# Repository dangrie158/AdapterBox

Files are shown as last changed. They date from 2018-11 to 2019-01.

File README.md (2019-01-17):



# Adapter Box

A simple multiconnector Adapter Box to hopefully fulfill all connection needs. It features 2 Channels (e.g. +/-) and the following connectors:

- 1x 5.5mm / 2.1mm DC-Jack (center positive)
- 1x USB-A
- 1x Phoenix Contact MKDSN Screw Terminals (0.2" / 5.08mm Pitch)
- 4x (2 per Channel) 4mm Banana Jack
- 4x (2 per Channel) 6.3mm Spade Terminal Connector
- 2x (1 per Channel) 5.5mm / 6.3mm Contact Point (e.g. for Crocodile Clips)
- 1x BNC (vertical mounting)
- 12x (6 per Channel) Female Pinheader (0.1" / 2,57mm Pitch)
- 12x (6 per Channel) Male Pinheader (0.1" / 2,57mm Pitch)
- 1x Power LED

The Power LED is driven my an LM334 constant current source that can handle up to 40V and 20V in reverse polarity. If you plan on going any higher, don't populate the components.

## Renders
### Assembly
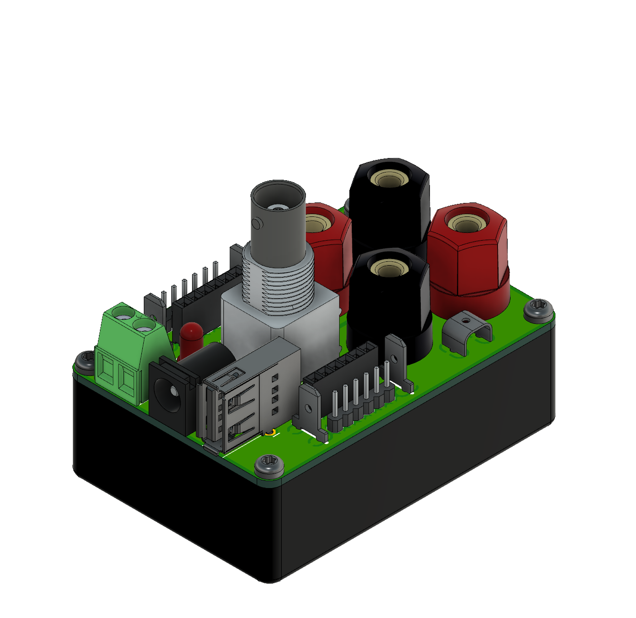
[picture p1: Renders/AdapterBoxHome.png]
Home View

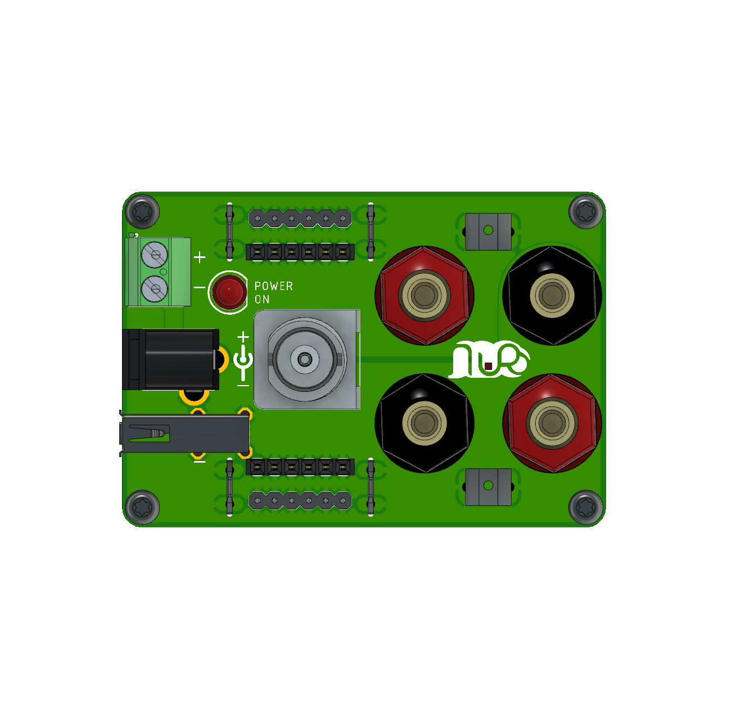
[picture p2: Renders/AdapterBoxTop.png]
Top View

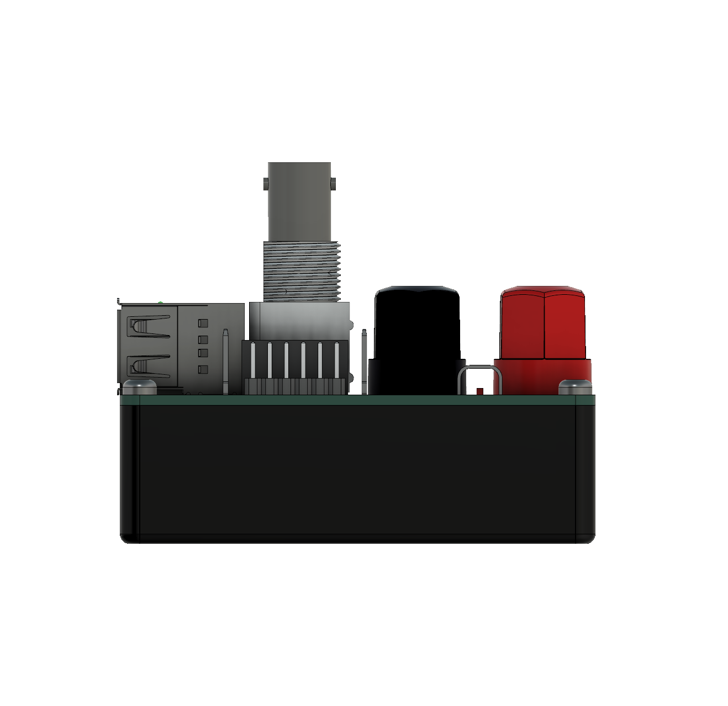
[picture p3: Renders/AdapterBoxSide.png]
Side View


### Board
#### Topside:
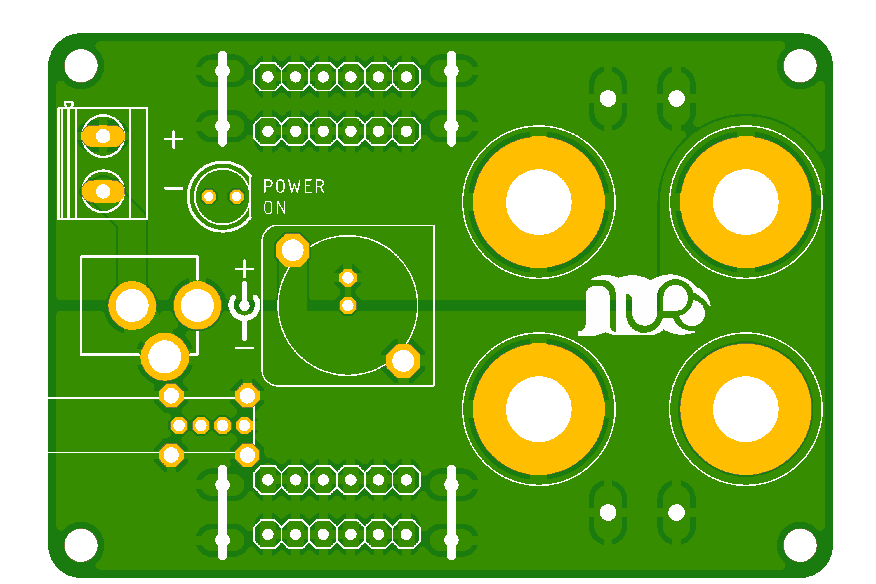
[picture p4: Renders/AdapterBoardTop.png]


#### Bottomside:
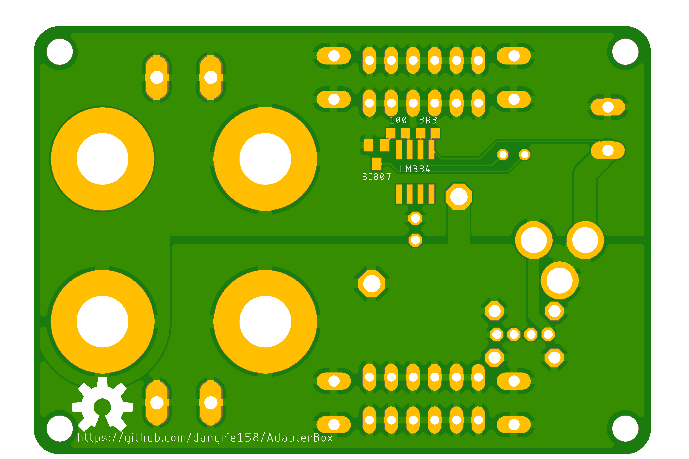
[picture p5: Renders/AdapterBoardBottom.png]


### BOM
For a Spreadsheet BOM, see [BOM.xlsx](BOM.xlsx).

The full BOM is currently only available from CONRAD Electronic, however for most Parts you should be able to easily find a replacement (see the Spreadsheet for some Digikey Part#s). Only the Case could be a bit hard to find elsewhere, but it is not mandatory to have (make one from Acrylic sheets for example).

| | Qty | Manufacturer | Manufacturer Part No. | Order-No. | Price (1) | Price (10) | Extended Price (1) |
|---|-----|---|---|---|---|---|---|
| BNC Jack | 1 | TRU-Components | 730413 | 1566143 - 62 | 3,44 | 3,24 | 3,44 |
| Case | 1 | TRU-Components | TC-2024 SW203 | 1588559 - 62 | 2,86 | 2,74 | 2,86 |
| Connector Straight | 4 | TE Connectivity | 726386-2 | 808428 - 62  | 0,21 | 0,19 | 0,84 |
| Connector Bridge | 2 | Vogt | 1098a.68 | 739844 - 62  | 0,09 | 0,08 | 0,18 |
| Pinheader Female | 2 | Connfly | 1498356 | 1498356 - 62 | 0,12 | 0,09 | 0,24 |
| Pinheader Male | 2 | Connfly | 1390113 | 1390113 - 62 | 0,12 | 0,09 | 0,24 |
| Contact Plug | 1 | Phoenix Contact | 1758018 | 743603 - 62  | 0,42 | 0,41 | 0,42 |
| USB-A | 1 | econ-connect | USBBUVA | 1311468 - 62 | 0,91 | 0,85 | 0,91 |
| Contact Screw | 1 | Phoenix Contact | 1729018 | 743530 - 62  | 0,54 | 0,52 | 0,54 |
| Banana Jack Black  | 2 | Schützinger | BU 403 sz | 737657 - 62  | 1,3 | 1,18 | 2,6 |
| Banana Jack Red | 2 | Schützinger | BU 403 rt | 737672 - 62  | 1,3 | 1,18 | 2,6 |
| DC Jack | 1 | TRU-Components | 1582643 | 1582643 - 62 | 0,68 | 0,62 | 0,68 |
| LM334 | 1 | Texas Instruments | LM334M/NOPB | 1014051 - 62 | 0,65 | 0,58 | 0,65 |
| 36 Ohm 0603 | 1 | Samsung | RC1608F36R0CS | 436455 - 62  | 0,02 | 0,02 | 0,02 |
| 100 Ohm 0603 | 1 | TRU-Components | 1585242 | 1585242 - 62 | 0,02 | 0,02 | 0,02 |
| BC807 | 1 | Nexperia | BC807-25,215 | 1112884 - 62 | 0,2 | 0,19 | 0,2 |
| Power LED | 1 | Kingbright | L 53 LID | 146005 - 62  | 0,13 | 0,12 | 0,13 |
| | | | | | | | |
| | | | | | | **Total**  | **16,2** |

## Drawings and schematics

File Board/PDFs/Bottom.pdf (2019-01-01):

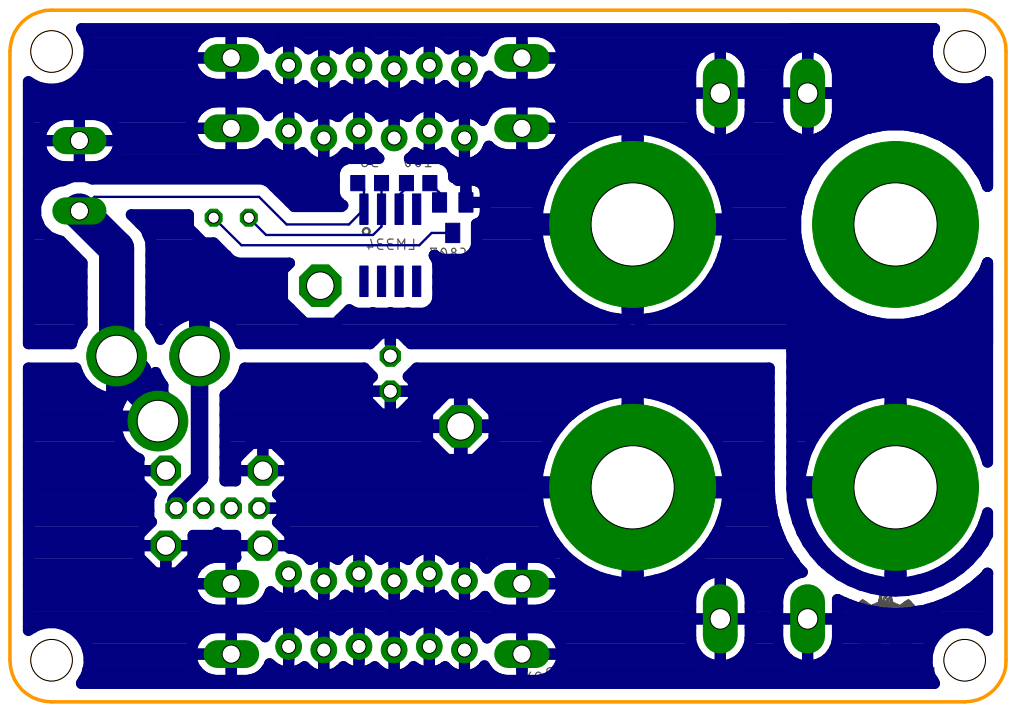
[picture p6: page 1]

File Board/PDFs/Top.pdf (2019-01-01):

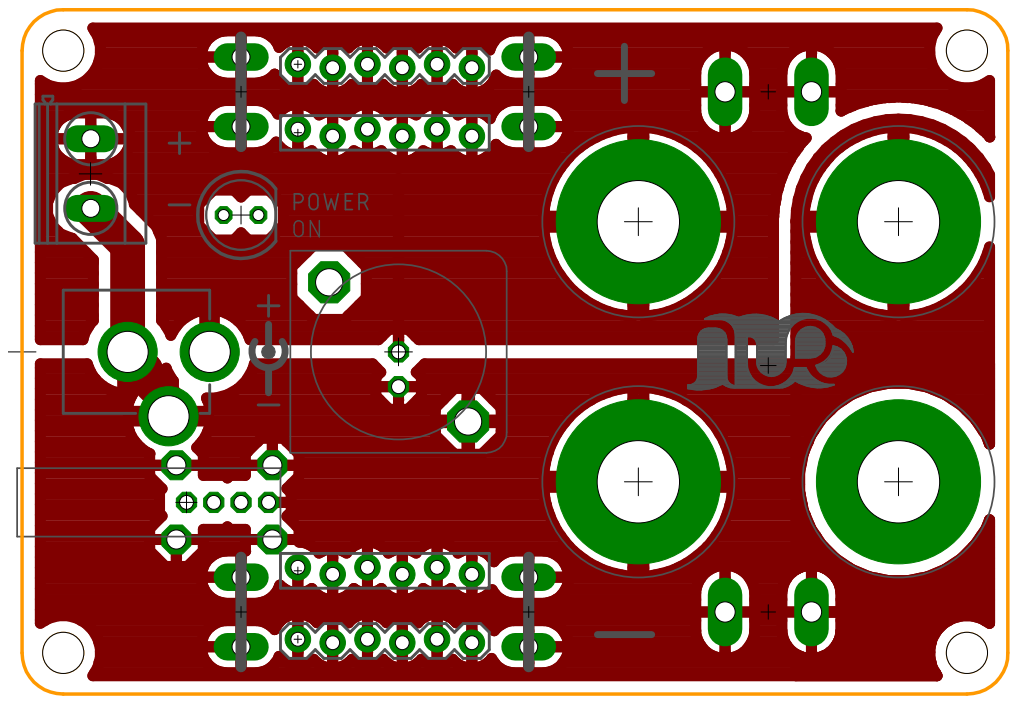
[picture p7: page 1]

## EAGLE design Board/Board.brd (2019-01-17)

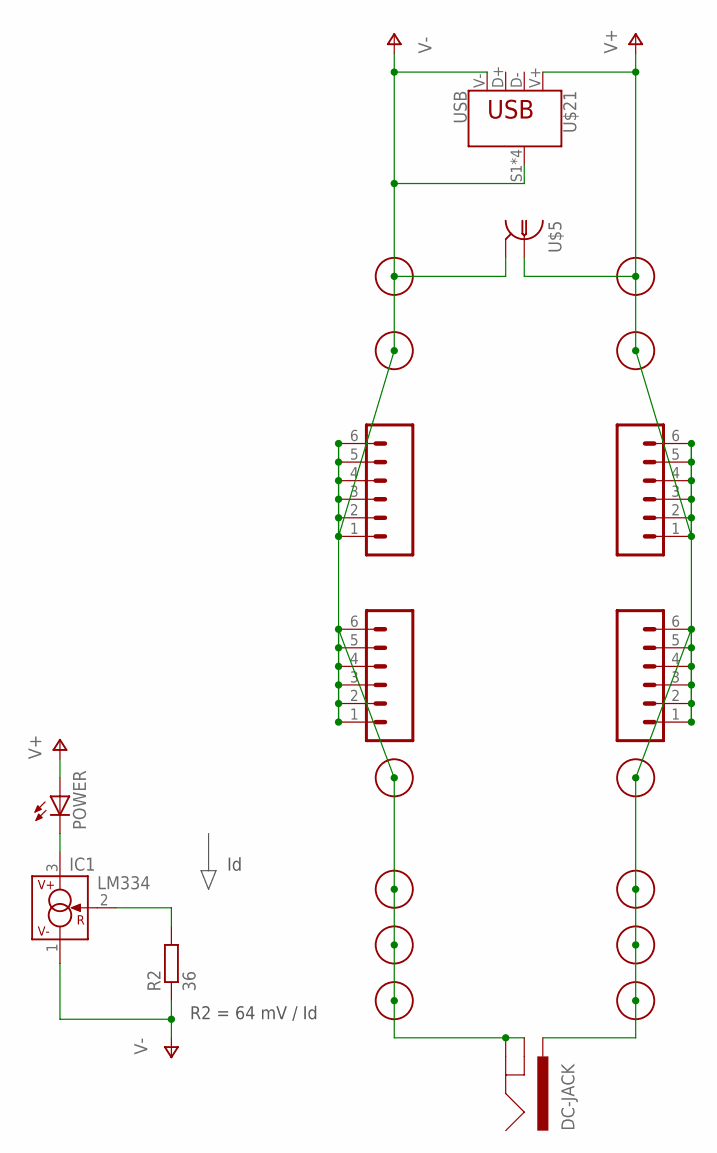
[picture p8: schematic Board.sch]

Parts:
IC1: LM334; SO08
POWER: LED5MM
R2: 36; R0603
U$1, U$3: 6MM-BANANA-PLUGSCREW-BLACK; 6MM-TERMINAL-POST-BLACK
U$2, U$4: 6MM-BANANA-PLUGSCREW-RED; 6MM-TERMINAL-POST-RED
U$5: BNC-VTE-1-1337541-0; BNC-V
U$6, U$7: PINHEADER-1X6MALE_LOCK; 1X06_LOCK
U$8, U$9: PINHEADER-1X6FEMALE_LOCK; 1X06_FEMALE_LOCK.010
U$10: TERMINAL-BLOCK-2; MKDSN1,5/2-5,08
U$12: DC-JACK; POWER_JACK_PTH
U$14, U$15, U$18, U$19: TERMINAL-1; TE-726386
U$16, U$17: TERMINAL-1BRIDGE; VOGT-1098A.68
U$21: USB; ECON-USBBUVA

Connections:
unnamed: IC1.2 (R), R2.2
unnamed: IC1.3 (V+), POWER.K (C)
V+: POWER.A, U$2.P$1, U$4.P$1, U$5.CONDUCTOR1 (C), U$7.1, U$7.2, U$7.3, U$7.4, U$7.5, U$7.6, U$9.1, U$9.2, U$9.3, U$9.4, U$9.5, U$9.6, U$10.1, U$12.PWR, U$15.P$1, U$15.P$2, U$16.P$1, U$16.P$2, U$19.P$1, U$19.P$2, U$21.V+ (VBUS)
V-: IC1.1 (V-), R2.1, U$1.P$1, U$3.P$1, U$5.CONDUCTOR2 (S), U$5.SHIELD1 (S), U$5.SHIELD2 (S), U$6.1, U$6.2, U$6.3, U$6.4, U$6.5, U$6.6, U$8.1, U$8.2, U$8.3, U$8.4, U$8.5, U$8.6, U$10.2, U$12.GND, U$12.GNDBREAK, U$14.P$1, U$14.P$2, U$17.P$1, U$17.P$2, U$18.P$1, U$18.P$2, U$21.S1 (SHIELD), U$21.S2 (SHIELD), U$21.S3 (SHIELD), U$21.S4 (SHIELD), U$21.V- (GND)

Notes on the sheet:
R2 = 64 mV / Id

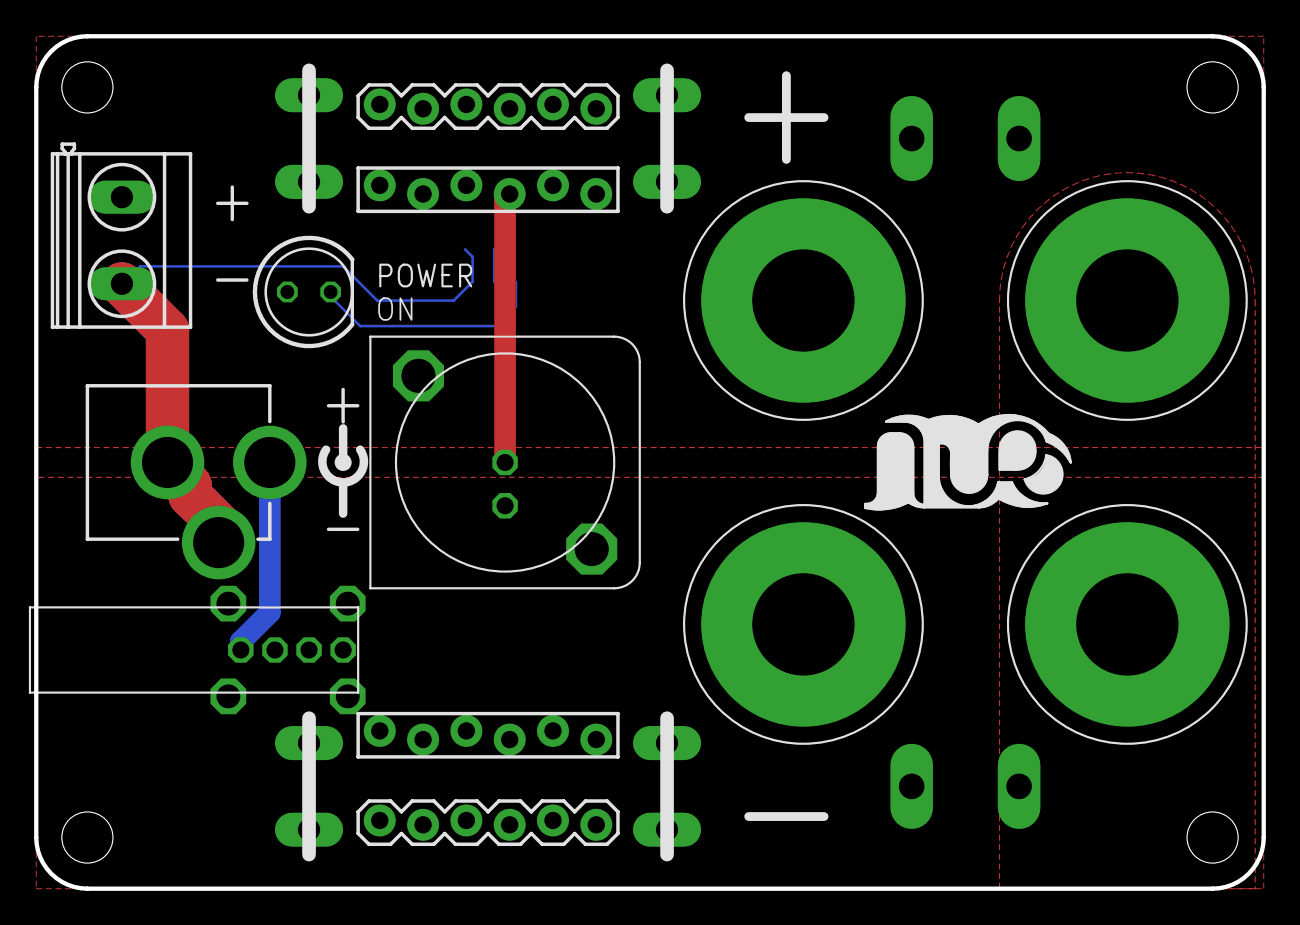
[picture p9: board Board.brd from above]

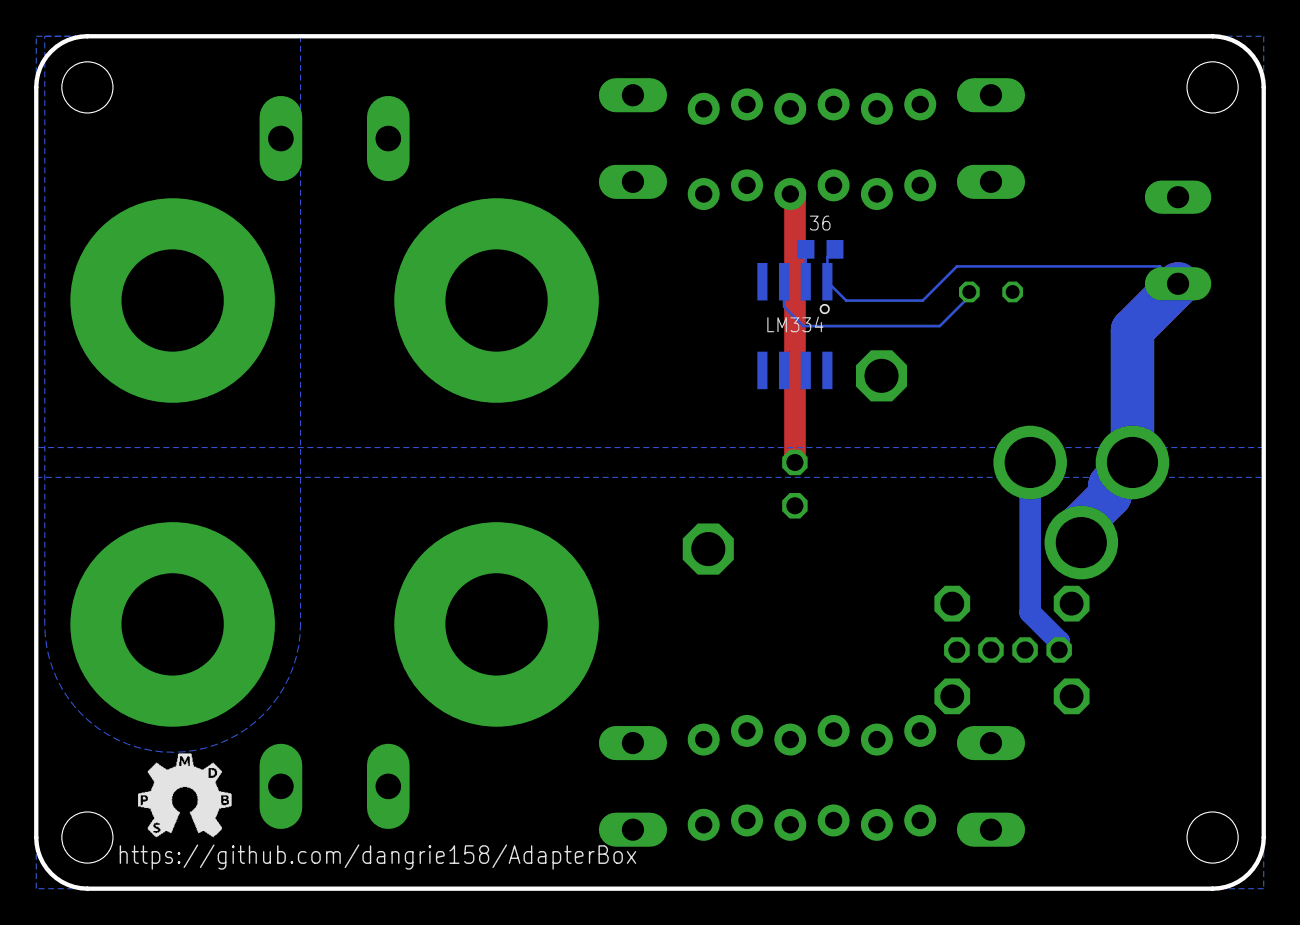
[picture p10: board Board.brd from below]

Board: 2 copper layers, 72.0 x 50.0 mm, 22 parts (2 on the bottom side), 4 nets.

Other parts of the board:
U$13: LOGO-SILKSCREEN

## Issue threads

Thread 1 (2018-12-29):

BOM - LED?

timgiles, 2018-12-29:
BOM is missing the LED

dangrie158, 2019-01-01:
Although any LED with 2mA If should work, I added a suitable one with [c4b2034b](https://github.com/dangrie158/AdapterBox/commit/c4b2034b653d3cadd883d63f2ce0771367618c50)

Closed 2019-01-01.

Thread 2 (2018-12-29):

PCB improvement

timgiles, 2018-12-29:
It would help if you put a dot for locating pin 1 on the LM (bottom side)

dangrie158, 2019-01-01:
Added pin 1 marker with [ad0f14c](
https://github.com/dangrie158/AdapterBox/commit/ad0f14c2aa7ee1bcba8b9b124a42b0f54238edc9)

Closed 2019-01-01.

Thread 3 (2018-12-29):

Not enough space for BNC locator pins

timgiles, 2018-12-29:
Every other part seemed to have the correct size hole(s) and spacing - but for me, the given BNC connector would not fit the two locator pins at the same time. I suspect therefore that your layout for the part is incorrect. To confirm, I ordered the exact BNC from Conrad.

dangrie158, 2019-01-01:
Thanks for the feedback. This should be fixed by [a832ae4](https://github.com/dangrie158/AdapterBox/commit/a832ae4d49a8491ea860509758d1a86a95824ddd).

Closed 2019-01-01.

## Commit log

2018-11-10 added Board File
    [Board.brd, Board.sch]
2018-11-10 added PDFs for Board Layout
2018-11-10 added current Gerbers
2018-11-10 added BOM
    [BOM.xlsx]
2018-11-10 fixed layout error in README BOM table
2018-11-10 moved BNC to center for better access to lower profile connectors
    [BOM.xlsx, Board.brd]
2018-11-12 implemented various suggestions from the forum post
    [Board.brd, Board.sch]
2018-11-12 updated renders and production gerbers to latest version
2018-11-12 updated BOM and README
    [BOM.xlsx]
2018-11-19 fixed BNC pinout
    [Board.brd, Board.sch]
2018-12-01 updated BNC footprint
    [Board.brd, Board.sch]
2018-12-01 updated pinheader 3d models
    [Board.brd, Board.sch]
2018-12-09 increased constant current feedback resistor
    [BOM.xlsx, Board.brd, Board.sch]
2019-01-01 reverted to old bnc footprint
    [Board.brd, Board.sch]
2019-01-01 added pin 1 marker for lm334
    [Board.brd]
2019-01-01 added LED to BOM
    [BOM.xlsx]
2019-01-01 updated gerbers and PDFs with new version
    [Board.brd]
2019-01-17 updated constant current source for power LED
    [Board.brd, Board.sch]
